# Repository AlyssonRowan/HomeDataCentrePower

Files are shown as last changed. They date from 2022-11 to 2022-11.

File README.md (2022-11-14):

Powering a Home Data Centre Project
===================================

Installation and power management for a home datacentre
-------------------------------------------------------

**About:**
This is the repository for the files accompanying an ongoing hardware project, where I install a home network server stack, and build in network power remote control and monitoring into an existing home network. The project article is on Blogger.

The project will hopefully give insight into power and environmental monitoring, power control and non-IoT network remote control and monitoring. The monitoring alone could be applied to the multiple mains circuits in a domestic environment, giving a more granular measurement of where power is being used than a _Smart Meter_ can give.

Files for the circuit boards comprising the hardware aspects of the project are placed together, with separate directories for each PCB.

Construction notes for each PCB are included with the files for that PCB.

Project Blog at: https://alyssonrowanprojects.blogspot.com/p/powering-home-datacentre.html

Presently, the project is only suitable for single-phase supplies. Hopefully, there will be a 3-phase version at some point in the future.

Project:
-------

Copyright (c) Alysson Rowan, 2022

Hardware designs are released as Open Source Hardware under the
CERN Open Hardware Licence Version 2 - Permissive

All other materials are released under the
GNU GENERAL PUBLIC LICENSE Version 3

Datasheets are copyright their individual creators.
Some included software is copyright by individual creators.

Disclaimer:
----------

No liability express or implied will be accepted in conjunction with
use of any of the information, software or designs presented here.
The user is entirely responsible for their use and interpretation of same.

.

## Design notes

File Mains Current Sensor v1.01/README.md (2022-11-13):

Mains Current Sensor sub-project.
v1.01 Copyright(c), 2022 Alysson Rowan
Released under the 
CERN Open Hardware Licence Version 2 - Permissive

DISCLAIMER:
Hardware designs are supplied 'as is' with no liability or responsibility 
accepted for any damages, injury etc. no matter however caused. The user 
is entirely responsible for their use of these designs.

\README.md				This File

\Bill of Materials.rtf                  Component Schedule for PCB
\Construction notes.rtf                 PCB Build notes
\Mains Current Sensor.GBR\		[DIR] PCB Gerber Files
\Mains Current Sensor.GBR.zip		PCB Gerber Files Archive
\Mains Current Sensor.PCB.dip		DipTrace PCB source file
\Mains Current Sensor.PCB.png		PCB X-ray View
\Mains Current Sensor.SCH.dch		DipTrace Schematic source file
\Mains Current Sensor.SCH.png		Schematic View

13 Nov 2022 - V1.01 - Initial commit of Current Sensor Board

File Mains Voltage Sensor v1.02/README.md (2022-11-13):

Mains Voltage Sensor sub-project.
v1.02 Copyright(c), 2022 Alysson Rowan
Released under the 
CERN Open Hardware Licence Version 2 - Permissive

DISCLAIMER:
Hardware designs are supplied 'as is' with no liability or responsibility 
accepted for any damages, injury etc. no matter however caused. The user 
is entirely responsible for their use of these designs.

\README.md				This File

\Bill of Materials.rtf                  Component Schedule for PCB
\Construction notes.rtf                 PCB Build notes
\Mains Voltage Sensor.GBR\		[DIR] PCB Gerber Files
\Mains Voltage Sensor.GBR.zip		PCB Gerber Files Archive
\Mains Voltage Sensor.PCB.dip		DipTrace PCB source file
\Mains Voltage Sensor.PCB.png		PCB X-ray View
\Mains Voltage Sensor.SCH.dch		DipTrace Schematic source file
\Mains Voltage Sensor.SCH.png		Schematic View

 8 Nov 2022 - V1.02 - Initial commit of Voltage Sensor Board
12 Nov 2022         - Minor corrections to PCB files, added construction notes

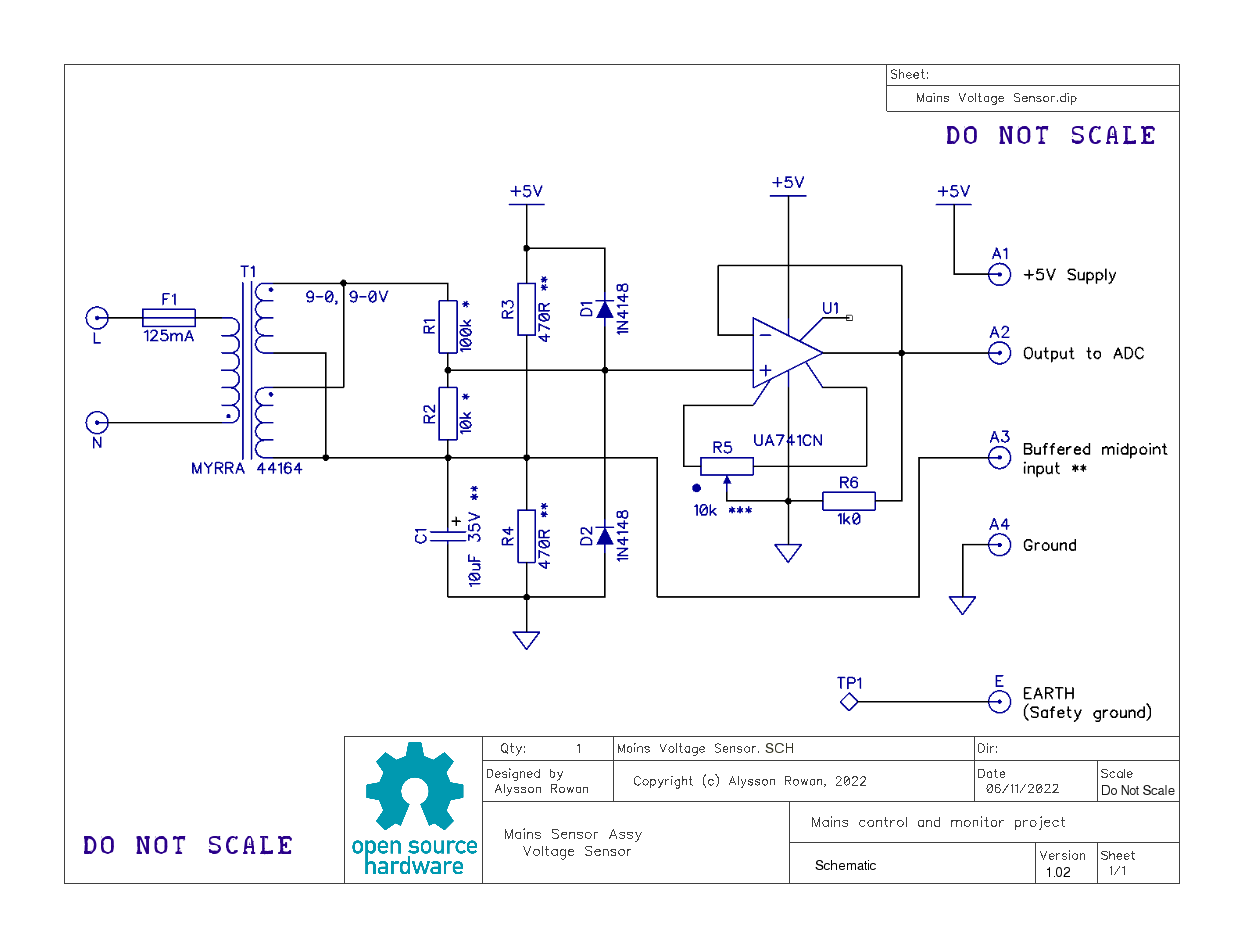
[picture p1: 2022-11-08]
Mains Voltage Sensor v1.02/Mains Voltage Sensor.SCH.png

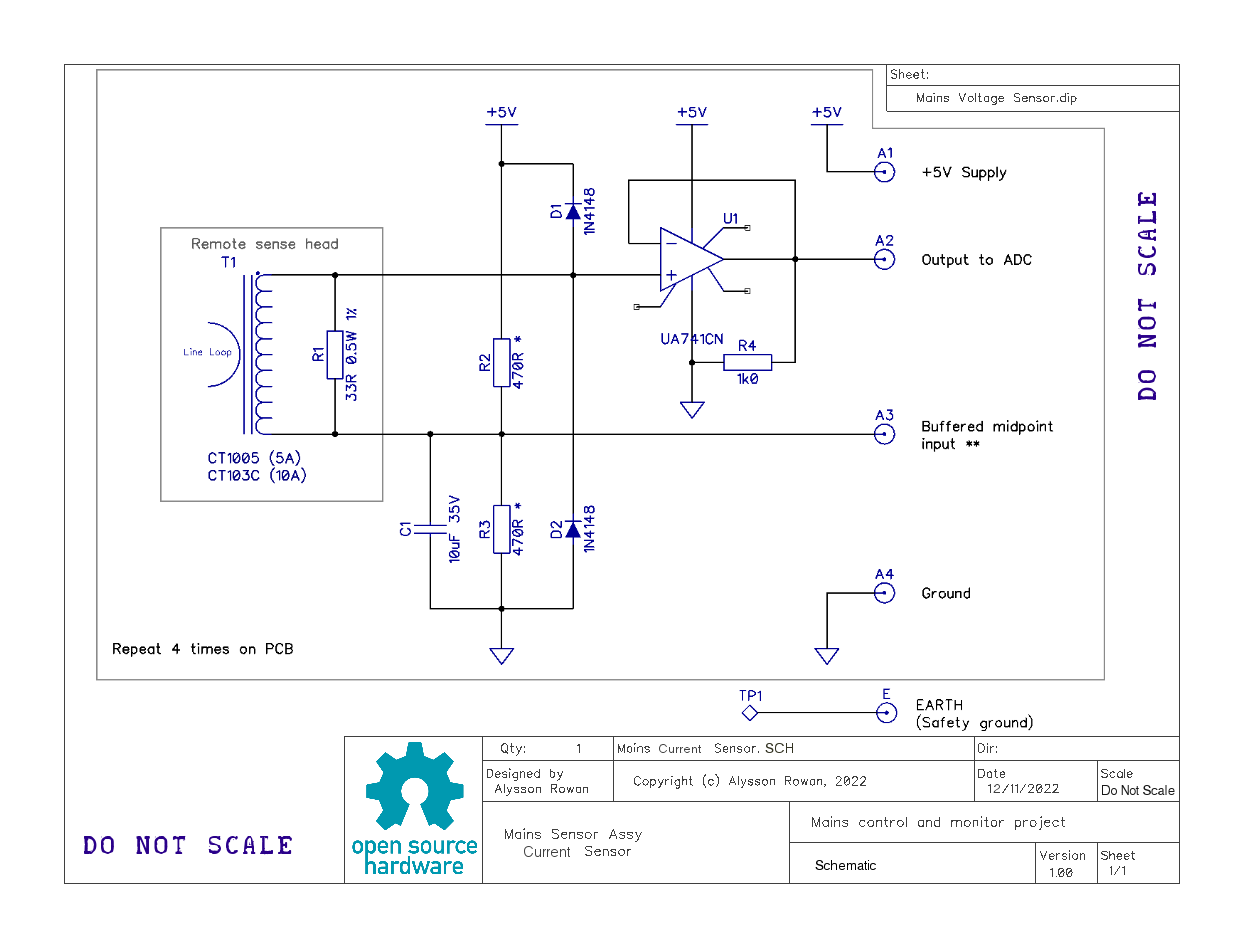
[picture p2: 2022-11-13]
Mains Current Sensor v1.01/Mains Current Sensor.SCH.png

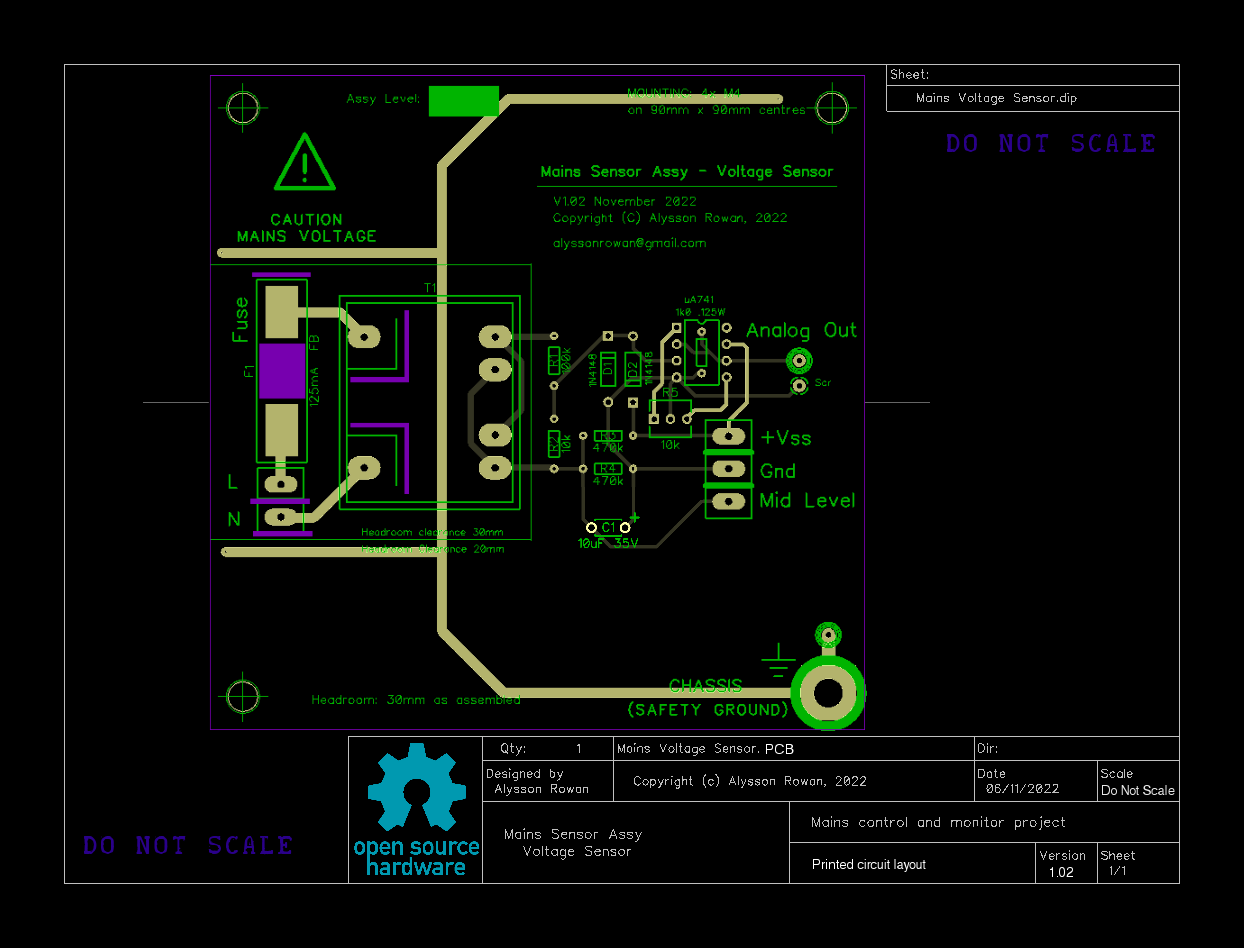
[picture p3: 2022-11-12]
Mains Voltage Sensor v1.02/Mains Voltage Sensor.PCB.png

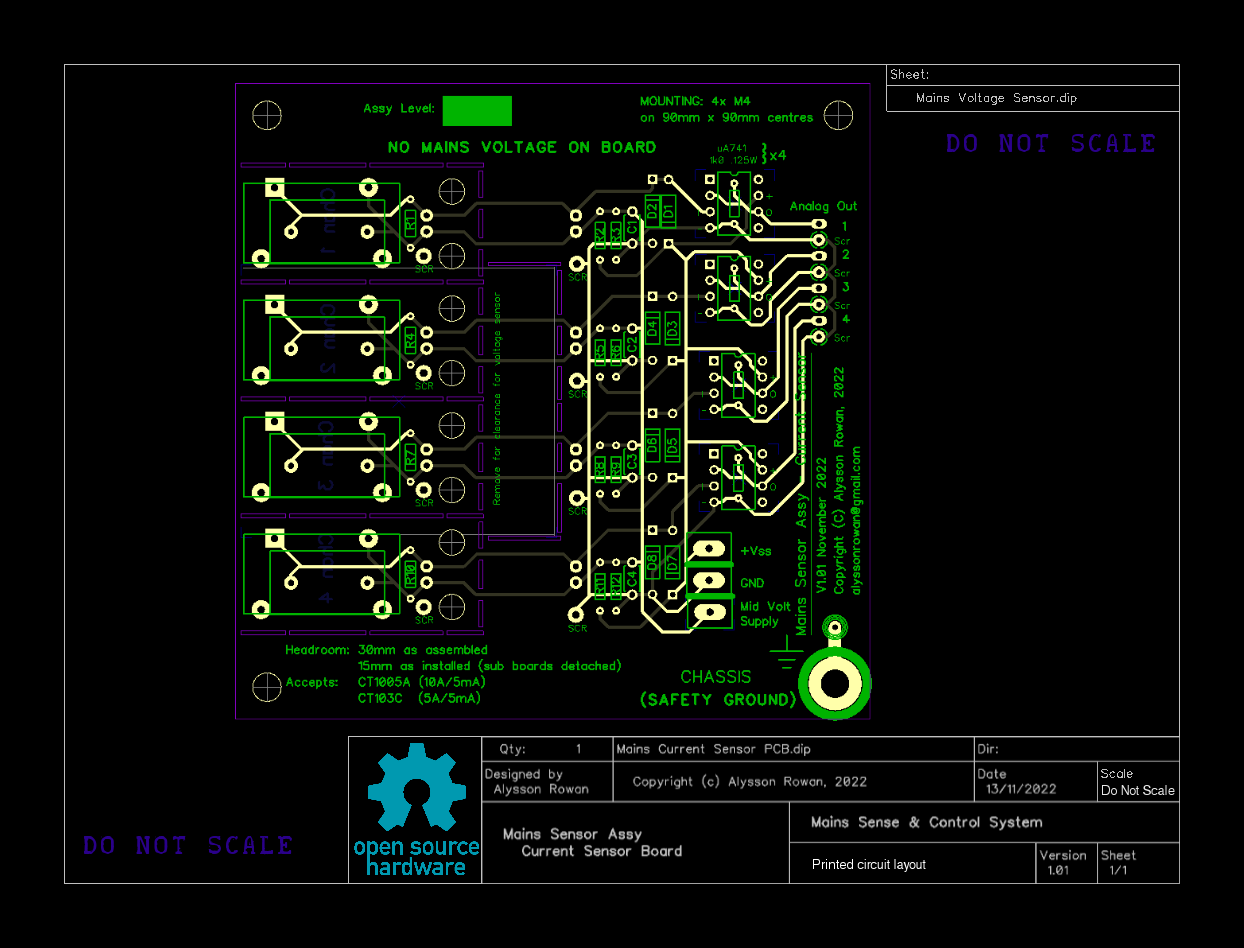
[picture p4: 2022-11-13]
Mains Current Sensor v1.01/Mains Current Sensor.PCB.png

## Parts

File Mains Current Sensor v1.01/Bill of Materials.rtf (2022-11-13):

Bill of Materials for
Mains Sensor Assy - Current Sensor
V 1.01 November 2022
Copyright (c) Alysson Rowan, 2022
alyssonrowan@gmail.com
Design released as Open Source Hardware under the
CERN Open Hardware Licence Version 2 - Permissive
No liability accepted.

Resistors
R1, R4, R7, R10 33Ω 0.5W 1% Metal Oxide or Metal Film, Axial leads
R2, R3, R5, R6 470kΩ 0.25W 1% Metal Oxide or Metal Film, Axial leads
R8, R9, R11, R12
R13, R14, R15, R16 1kΩ 0.125W 1% Metal Oxide or Metal Film, Axial Leads
Capacitors
C1, C2, C3, C4 100nF Polyester
Diodes
D1, D2, D3, D4 1N4148 / 1N915 or similar
D5, D6, D7, D8
Integrated Circuits
U1, U2, U3, U4 µA741 General Purpose Op Amp, 8-pin DIP with sockets
Current Transformers
TR1 to TR4 CT1005, CT103C or similar

AR - Nov 2022

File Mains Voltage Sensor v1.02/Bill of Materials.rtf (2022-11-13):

Bill of Materials for
Mains Sensor Assy - Current Sensor
V 1.00 November 2022
Copyright (c) Alysson Rowan, 2022
alyssonrowan@gmail.com
Design released as Open Source Hardware under the
CERN Open Hardware Licence Version 2 - Permissive
No liability accepted.

Resistors
R1 100kΩ 0.25W 1% Metal Oxide or Metal Film, Axial leads
R2 10kΩ 0.25W 1% Metal Oxide or Metal Film, Axial leads
R3, R4 470Ω 0.25W 1% Metal Oxide or Metal Film, Axial Leads
R6 1kΩ 0.125W 1% Metal Oxide or Metal Film, Axial Leads
R5 10k Preset Potentiometer
Capacitors
C1 10µF 35V Electrolyitc or 100nF Polyester (see contruction notes)
Dioces
D1, D2 1N4148 ot 1N915, axial leads
Integrated Circuits
U1 µA741 General Purpose Op Amp, 8-pin DIP with socket
Transformer
TR1 MYRRA 44164
Fuse
F1 125mA 240V 20mm Fast or standard Blow

AR - Nov 2022

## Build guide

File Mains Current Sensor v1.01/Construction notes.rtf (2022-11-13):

Construction Notes for
Mains Sensor Assy - Current Sensor
V 1.01 November 2022
Copyright (c) Alysson Rowan, 2022
alyssonrowan@gmail.com
Design released as Open Source Hardware under the
CERN Open Hardware Licence Version 2 - Permissive
No liability accepted.

THIS CIRCUIT BOARD MUST BE EARTHED
Earthing may be applied via the bottom-right mounting hole (M4 ring terminal) or a wired connection to the through-hole pad adjacent to it.
There should be no direct connection to mains voltages using this board.
The circuit board is designed for through-hole mounted components throughout. This is mainly because it is easier for beginners and for the older generation to make those joints without resorting to magnifying glasses and surface-soldering tools.
The resistors are all 1/4 W metal oxide devices except for R13 to R16 which is 1/8W (0.125W) and R1, R4, R7, R10 which are 1/2 W (0.5W)
The Analog Out connections may be wired to the board or made using a duPont connector and header pins. Similarly, the power supply pins.
IC1-4 (µA741 Op Amp) should be installed using 8-pin DIL sockets ; R13, R14, R15, R16 (1k0, 0.125W )should be mounted in the recesses below the sockets. If this is not possible, then mount the resistors on the underside of the PCB.
If a mid-level buffered supply is used, then R2, R3, R5, R6, R8, R9, R11, R12 should be omitted.
Sensor Heads:
The four sensor head breakouts should be detached for installation in a remote mains box. Screened stage-grade microphone cable (2-core, overall screened) should be used to connect. By removing the small filler panel, this board will fit above the Voltage Sensor board without compromising safety.
Board Mounting:
The board may be mounted using M4 standoffs, and must be mounted at least 6mm above an insulated surface (10mm above a conductive surface). Use either metal or nylon standoffs.
The headroom required by the board is marked. 30mm to clear the specified transformers, 15mm if the the current sensor heads are detached.
The four M4 mounting holes are on 90mm centres

The rectangle marked "Assy Level" is intended for writing the position (layer number) of the PCB in a stack of boards on common standoffs.

A suitably populated single board will provide current sensing for a single 3-phase (3- or 4-wire) supply, or four single phase supplies.
AR - Nov 2022

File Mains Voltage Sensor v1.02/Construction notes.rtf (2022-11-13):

Construction Notes for
Mains Sensor Assy - Voltage Sensor
V 1.02 November 2022
Copyright (c) Alysson Rowan, 2022
alyssonrowan@gmail.com
Design released as Open Source Hardware under the
CERN Open Hardware Licence Version 2 - Permissive
No liability accepted.

THIS CIRCUIT BOARD MUST BE EARTHED
Earthing may be applied via the bottom-right mounting hole (M4 ring terminal) or a wired connection to the through-hole pad adjacent to it.

The circuit board is designed for through-hole mounted components throughout. This is mainly because it is easier for beginners and for the older generation to make those joints without resorting to magnifying glasses and surface-soldering tools.
The connector for the Line and Neutral wires of the mains supply is a side-entry screw terminal block.
The fuse (in the Line side of the supply) is a 125mA standard or fast blow, 20mm bodied fuse which is soldered directly to the PCB.
The PCB mount isolating transformer is MYRRA 44164 (220/240V - 0-9, 0-9V) PCB transformer. Using other models will require care and may require editing of the transformer footprint.
The resistors are all 1/4 W metal oxide devices except for R6 which is 1/8W (0.125W)
The Analog Out connection may be wired to the board or made using a duPont connector and header pins. Similarly, the power supply pins.

IC1 (µA741 Op Amp) should be installed using an 8-pin DIL socket; R6 should be mounted in the recess below the socket. If this is not possible, then mount the resistor on the underside of the PCB.

The offset Null adjustment pot (R5) is optional, and should only be installed and adjusted if the highest precision is required.

If a mid-level buffered supply is used, then R3 and R4 should be omitted, and C1 (10µF, 35V electrolytic) be replaced with a 100nF polyester capacitor.

Board Mounting:
The board may be mounted using M4 standoffs, and must be mounted at least 6mm above an insulated surface (10mm above a conductive surface). Use either metal or nylon standoffs.
The headroom required by the board is marked. 30mm to clear the specified transformer, 20mm if the next layer has a cut-out for the transformer.
The four M4 mounting holes are on 90mm centres

The rectangle marked "Assy Level" is intended for writing the position (layer number) of the PCB in a stack of boards on common standoffs.

AR - Nov 2022

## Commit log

2022-11-06 Update README.md
    A project covering the installation and power management for a home datacentre.
    More than just software.
2022-11-07 Create VoltageSensing.index.tar.txt
    Test file
2022-11-08 Voltage Sensor PCB added
    [1 - Top.gbr, 2 - Bottom.gbr, Board.gbr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]
2022-11-12 Minor corrections to Voltage Sensor files;
2022-11-13 Added datasheets. First commit for Current Sensor. Several other tweaks.
    [1 - Top.gbr, 2 - Bottom.gbr, Board.gbr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]
